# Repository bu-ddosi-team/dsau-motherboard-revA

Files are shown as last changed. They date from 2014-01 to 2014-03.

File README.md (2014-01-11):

# dSAU Motherboard (Rev. A)

## Directory Structure

- lib     : Contains Parts Library Files
- src     : Contains Schematics and PCBs
- docs    : Contains documentation and notes (PDFs of schematic/PCB, etc)
- prod    : Contains production files (Gerbers)

## Library Contents

### PcbLib

- VQFN64 (for ADS62P49)
- FCI_61083-101400LF
- MicroZed Mating Side

### SchLib

- ADS62P49
- MicroZed

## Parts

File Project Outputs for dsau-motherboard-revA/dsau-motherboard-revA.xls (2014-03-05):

Designator | Quantity | Description | Manufacturer 1 | Manufacturer Part Number | Supplier 1 | Supplier Part Number 1
C1_1 | 1.0 | Capacitor | Yageo | CC0603ZRY5V9BB104 | Digi-Key | 311-1343-1-ND
C1_2 | 1.0 | Capacitor | Yageo | CC0603ZRY5V9BB104 | Digi-Key | 311-1343-1-ND
C2_1 | 1.0 | Capacitor | Yageo | CC0603ZRY5V9BB104 | Digi-Key | 311-1343-1-ND
C2_2 | 1.0 | Capacitor | Yageo | CC0603ZRY5V9BB104 | Digi-Key | 311-1343-1-ND
C3_1 | 1.0 | Capacitor | Yageo | CC0603ZRY5V9BB104 | Digi-Key | 311-1343-1-ND
C3_2 | 1.0 | Capacitor | Yageo | CC0603ZRY5V9BB104 | Digi-Key | 311-1343-1-ND
C4 | 1.0 | Polarized Capacitor (Surface Mount) | AVX Corporation | TPSA336K006R0600 | Digi-Key | 478-1755-1-ND
C5 | 1.0 | Capacitor | Yageo | CC0603ZRY5V9BB104 | Digi-Key | 311-1343-1-ND
C6 | 1.0 | Polarized Capacitor (Surface Mount) | AVX Corporation | TPSA336K006R0600 | Digi-Key | 478-1755-1-ND
C7 | 1.0 | Capacitor | Yageo | CC0603ZRY5V9BB104 | Digi-Key | 311-1343-1-ND
C8 | 1.0 | Capacitor | Yageo | CC0805KKX7R7BB105 | Digi-Key | 311-1365-1-ND
C9 | 1.0 | Capacitor | Kemet | C0603C103K3GACTU | Digi-Key | 399-8987-1-ND
C10 | 1.0 | Capacitor | Samsung Electro-Mechanics America, Inc | CL10C100JB8NCNC | Digi-Key | 1276-2154-1-ND
C11 | 1.0 | Capacitor | Yageo | CC0805KKX7R7BB105 | Digi-Key | 311-1365-1-ND
C12 | 1.0 | Capacitor | Yageo | CC0603ZRY5V9BB104 | Digi-Key | 311-1343-1-ND
C13 | 1.0 | Capacitor | Kemet | C0603C103K3GACTU | Digi-Key | 399-8987-1-ND
C14 | 1.0 | Capacitor | Samsung Electro-Mechanics America, Inc | CL10C100JB8NCNC | Digi-Key | 1276-2154-1-ND
C15 | 1.0 | Polarized Capacitor (Surface Mount) | AVX Corporation | TPSA336K006R0600 | Digi-Key | 478-1755-1-ND
C16 | 1.0 | Capacitor | Kemet | C0603C103K3GACTU | Digi-Key | 399-8987-1-ND
C17 | 1.0 | Capacitor | Yageo | CC0603ZRY5V9BB104 | Digi-Key | 311-1343-1-ND
C18 | 1.0 | Capacitor | Yageo | CC0603ZRY5V9BB104 | Digi-Key | 311-1343-1-ND
C19 | 1.0 | Capacitor | Yageo | CC0603ZRY5V9BB104 | Digi-Key | 311-1343-1-ND
C20 | 1.0 | Capacitor | Yageo | CC0603ZRY5V9BB104 | Digi-Key | 311-1343-1-ND
C21 | 1.0 | Capacitor | Yageo | CC0603ZRY5V9BB104 | Digi-Key | 311-1343-1-ND
C22 | 1.0 | Polarized Capacitor (Surface Mount) | Vishay Sprague | TL8A0107M010C | Digi-Key | 718-1921-1-ND
C23 | 1.0 |  | TDK Corporation | C1005X5R1A104K | Digi-Key | 445-1265-1-ND
C24 | 1.0 | GRM1555C1E5R1CA0 | Kemet | C0402C519C5GACTU | Digi-Key | 399-8972-1-ND
C25 | 1.0 | GRM31CR60J476ME1 | Murata Electronics North America | GRM31CR60J476ME19L | Digi-Key | 490-3907-1-ND
C26 | 1.0 | C3225X5R1A226M | TDK Corporation | C3225X5R1A226M | Digi-Key | 445-1403-1-ND
C27 | 1.0 | GRM155R61A105KE1 | Murata Electronics North America | GRM155R61A105KE15D | Digi-Key | 490-3890-1-ND
C28 | 1.0 | GRM155R71E822KA0 | Murata Electronics North America | GRM155R71E822KA01D | Digi-Key | 490-1311-1-ND
C29 | 1.0 | Capacitor | Samsung Electro-Mechanics America, Inc | CL10A106MQ8NNNC | Digi-Key | 1276-1119-1-ND
C30 | 1.0 |  | TDK Corporation | C1005X5R1A104K | Digi-Key | 445-1265-1-ND
C31 | 1.0 | Capacitor | TDK Corporation | C3216X5R0J686M160AB | Digi-Key | 445-14671-1-ND
C32 | 1.0 | GRM1555C1E5R1CA0 | Kemet | C0402C519C5GACTU | Digi-Key | 399-8972-1-ND
C33 | 1.0 | GRM31CR60J476ME1 | Murata Electronics North America | GRM31CR60J476ME19L | Digi-Key | 490-3907-1-ND
C34 | 1.0 | C3225X5R1A226M | TDK Corporation | C3225X5R1A226M | Digi-Key | 445-1403-1-ND
C35 | 1.0 | GRM155R61A105KE1 | Murata Electronics North America | GRM155R61A105KE15D | Digi-Key | 490-3890-1-ND
C36 | 1.0 | GRM155R71E822KA0 | Murata Electronics North America | GRM155R71E822KA01D | Digi-Key | 490-1311-1-ND
C37 | 1.0 | Capacitor | Yageo | CC0603ZRY5V9BB104 | Digi-Key | 311-1343-1-ND
C38 | 1.0 | Capacitor | Yageo | CC0603ZRY5V9BB104 | Digi-Key | 311-1343-1-ND
C39 | 1.0 | Capacitor | Yageo | CC0603ZRY5V9BB104 | Digi-Key | 311-1343-1-ND
C40 | 1.0 | Polarized Capacitor (Surface Mount) | AVX Corporation | TPSA336K006R0600 | Digi-Key | 478-1755-1-ND
C41 | 1.0 | Polarized Capacitor (Surface Mount) | Vishay Sprague | TL8A0107M010C | Digi-Key | 718-1921-1-ND
C42 | 1.0 | Capacitor | Yageo | CC0603ZRY5V9BB104 | Digi-Key | 311-1343-1-ND
C43 | 1.0 | Capacitor | Yageo | CC0603ZRY5V9BB104 | Digi-Key | 311-1343-1-ND
C44 | 1.0 | Capacitor | Yageo | CC0603ZRY5V9BB104 | Digi-Key | 311-1343-1-ND
C45 | 1.0 | Capacitor | Yageo | CC0603ZRY5V9BB104 | Digi-Key | 311-1343-1-ND
C46 | 1.0 | Capacitor | Yageo | CC0603ZRY5V9BB104 | Digi-Key | 311-1343-1-ND
C47 | 1.0 | Capacitor | Yageo | CC0603ZRY5V9BB104 | Digi-Key | 311-1343-1-ND
C48 | 1.0 | Capacitor | Kemet | C0603C103K3GACTU | Digi-Key | 399-8987-1-ND
C49 | 1.0 | Capacitor | Samsung Electro-Mechanics America, Inc | CL10C100JB8NCNC | Digi-Key | 1276-2154-1-ND
C50 | 1.0 | Capacitor | Samsung Electro-Mechanics America, Inc | CL10C100JB8NCNC | Digi-Key | 1276-2154-1-ND
C51 | 1.0 | Capacitor | Samsung Electro-Mechanics America, Inc | CL10C100JB8NCNC | Digi-Key | 1276-2154-1-ND
C52 | 1.0 | Capacitor | Kemet | C0603C103K3GACTU | Digi-Key | 399-8987-1-ND
C53 | 1.0 | Capacitor | Kemet | C0603C103K3GACTU | Digi-Key | 399-8987-1-ND
C54 | 1.0 | Capacitor | Kemet | C0603C103K3GACTU | Digi-Key | 399-8987-1-ND
C55 | 1.0 | Polarized Capacitor (Surface Mount) | AVX Corporation | TPSA336K006R0600 | Digi-Key | 478-1755-1-ND
C56 | 1.0 | Capacitor | Yageo | CC0603ZRY5V9BB104 | Digi-Key | 311-1343-1-ND
C57 | 1.0 | Capacitor | Yageo | CC0603ZRY5V9BB104 | Digi-Key | 311-1343-1-ND
C58 | 1.0 | Capacitor | Kemet | C0603C103K3GACTU | Digi-Key | 399-8987-1-ND
C59 | 1.0 | Capacitor | Samsung Electro-Mechanics America, Inc | CL10C100JB8NCNC | Digi-Key | 1276-2154-1-ND
C60 | 1.0 | Capacitor | Yageo | CC0603ZRY5V9BB104 | Digi-Key | 311-1343-1-ND
C61 | 1.0 | Capacitor | Kemet | C0603C103K3GACTU | Digi-Key | 399-8987-1-ND
C62 | 1.0 | Capacitor | Yageo | CC0603ZRY5V9BB104 | Digi-Key | 311-1343-1-ND
C63 | 1.0 | Capacitor | Kemet | C0603C103K3GACTU | Digi-Key | 399-8987-1-ND
C64 | 1.0 | Capacitor | Yageo | CC0603ZRY5V9BB104 | Digi-Key | 311-1343-1-ND
C65 | 1.0 | Capacitor | Kemet | C0603C103K3GACTU | Digi-Key | 399-8987-1-ND
C66 | 1.0 | Capacitor | Yageo | CC0805KKX7R7BB105 | Digi-Key | 311-1365-1-ND
C67 | 1.0 | Capacitor | Yageo | CC0603ZRY5V9BB104 | Digi-Key | 311-1343-1-ND
C68 | 1.0 | Capacitor | Samsung Electro-Mechanics America, Inc | CL10C100JB8NCNC | Digi-Key | 1276-2154-1-ND
C69 | 1.0 | Polarized Capacitor (Surface Mount) | AVX Corporation | TPSA336K006R0600 | Digi-Key | 478-1755-1-ND
C70 | 1.0 | Capacitor | Yageo | CC0805KKX7R7BB105 | Digi-Key | 311-1365-1-ND
C71 | 1.0 | Capacitor | Yageo | CC0603ZRY5V9BB104 | Digi-Key | 311-1343-1-ND
C72 | 1.0 | Capacitor | Samsung Electro-Mechanics America, Inc | CL10C100JB8NCNC | Digi-Key | 1276-2154-1-ND
C73 | 1.0 | Capacitor | Yageo | CC0805KKX7R7BB105 | Digi-Key | 311-1365-1-ND
C74 | 1.0 | Capacitor | Yageo | CC0603ZRY5V9BB104 | Digi-Key | 311-1343-1-ND
C75 | 1.0 | Capacitor | Samsung Electro-Mechanics America, Inc | CL10C100JB8NCNC | Digi-Key | 1276-2154-1-ND
C76 | 1.0 | Capacitor | Yageo | CC0603ZRY5V9BB104 | Digi-Key | 311-1343-1-ND
C77 | 1.0 | Capacitor | Yageo | CC0603ZRY5V9BB104 | Digi-Key | 311-1343-1-ND
D1 | 1.0 | Typical INFRARED GaAs LED | Kingbright Company LLC | APT3216YC | Digi-Key | 754-1145-1-ND
D2 | 1.0 | Typical INFRARED GaAs LED | Kingbright Company LLC | APT3216YC | Digi-Key | 754-1145-1-ND
D3 | 1.0 | Typical INFRARED GaAs LED | Kingbright Company LLC | APT3216YC | Digi-Key | 754-1145-1-ND
D4 | 1.0 | The Blue source color devices are made with InGaN Light Emitting Diode. The Green source color devices are made with InGaN on Sapphire Light Emitting Diode. The Hyper Red source color devices are made with Al- GaInP on GaAs substrate Ligh | Loading... | APTF3216QBDZGSURKC | Mouser | 604-APTF3216QBDZGSUR
D5 | 1.0 | Typical INFRARED GaAs LED | Kingbright Company LLC | APL3015SGC-F01 | Digi-Key | 754-1111-1-ND
D6 | 1.0 | Typical INFRARED GaAs LED | Kingbright Company LLC | APL3015SGC-F01 | Digi-Key | 754-1111-1-ND
D7 | 1.0 | Typical INFRARED GaAs LED | Kingbright Company LLC | APL3015SGC-F01 | Digi-Key | 754-1111-1-ND
D8 | 1.0 | Typical INFRARED GaAs LED | Kingbright Company LLC | APL3015SGC-F01 | Digi-Key | 754-1111-1-ND
J1_1 | 1.0 | Header, 10-Pin, Dual row | Loading... | EJH-110-01-F-D-SM-LC | Samtec | EJH-110-01-F-D-SM-LC
J1_2 | 1.0 | Header, 10-Pin, Dual row | Loading... | EJH-110-01-F-D-SM-LC | Samtec | EJH-110-01-F-D-SM-LC
J1_3 | 1.0 | Header, 10-Pin, Dual row | Loading... | EJH-110-01-F-D-SM-LC | Samtec | EJH-110-01-F-D-SM-LC
J1_4 | 1.0 | Header, 10-Pin, Dual row | Loading... | EJH-110-01-F-D-SM-LC | Samtec | EJH-110-01-F-D-SM-LC
J1_5 | 1.0 | Header, 10-Pin, Dual row | Loading... | EJH-110-01-F-D-SM-LC | Samtec | EJH-110-01-F-D-SM-LC
J1_6 | 1.0 | Header, 10-Pin, Dual row | Loading... | EJH-110-01-F-D-SM-LC | Samtec | EJH-110-01-F-D-SM-LC
J2_1 | 1.0 | SMB Straight Connector | Molex Inc | 0731000207 | Digi-Key | WM5528-ND
J2_2 | 1.0 | SMB Straight Connector | Molex Inc | 0731000207 | Digi-Key | WM5528-ND
J2_3 | 1.0 | SMB Straight Connector | Molex Inc | 0731000207 | Digi-Key | WM5528-ND
J2_4 | 1.0 | SMB Straight Connector | Molex Inc | 0731000207 | Digi-Key | WM5528-ND
J2_5 | 1.0 | SMB Straight Connector | Molex Inc | 0731000207 | Digi-Key | WM5528-ND
J2_6 | 1.0 | SMB Straight Connector | Molex Inc | 0731000207 | Digi-Key | WM5528-ND
J3 | 1.0 | SMB Straight Connector | Molex Inc | 0733910060 | Digi-Key | WM5543-ND
J4 | 1.0 | Header, 3-Pin | CUI Inc | PJ-002BH | Digi-Key | CP-002BH-ND
J5 | 1.0 | Header, 2-Pin | Molex Inc | 0010085021 | Digi-Key | WM4333-ND
J6 | 1.0 | SMB Straight Connector | Molex Inc | 0733910320 | Digi-Key | WM8554-ND
J7 | 1.0 | SMB Straight Connector | Molex Inc | 0733910320 | Digi-Key | WM8554-ND
J8 | 1.0 | SMB Straight Connector | Molex Inc | 0733910060 | Digi-Key | WM5543-ND
J9 | 1.0 | Header, 13-Pin, Dual row | Loading... |  | Stock | 2x13 pin 100mil Headers
J10 | 1.0 | Header, 6-Pin | Loading... |  | Stock | 6 pin 100 mil
J11 | 1.0 | Header, 2-Pin | Molex Inc | 0010085021 | Digi-Key | WM4333-ND
J12 | 1.0 | Header, 2-Pin | Molex Inc | 0010085021 | Digi-Key | WM4333-ND
J13 | 1.0 | Header, 2-Pin | Molex Inc | 0010085021 | Digi-Key | WM4333-ND
JP1 | 1.0
JP2 | 1.0
JP3 | 1.0
JP4 | 1.0
JP5 | 1.0
JP6 | 1.0
L1 | 1.0 | Magnetic-Core Inductor | Laird-Signal Integrity Products | MI0603L301R-10 | Digi-Key | 240-2374-1-ND
L2 | 1.0 | Magnetic-Core Inductor | Laird-Signal Integrity Products | MI0603L301R-10 | Digi-Key | 240-2374-1-ND
L3 | 1.0 | Magnetic-Core Inductor | Laird-Signal Integrity Products | MI0603L301R-10 | Digi-Key | 240-2374-1-ND
L4 | 1.0 | SRN6045-2R2Y | Bourns Inc. | SRN6045-2R2Y | Digi-Key | SRN6045-2R2YCT-ND
L5 | 1.0 | SRN6045-2R2Y | Bourns Inc. | SRN6045-2R2Y | Digi-Key | SRN6045-2R2YCT-ND
L6 | 1.0 | Magnetic-Core Inductor | Laird-Signal Integrity Products | MI0603L301R-10 | Digi-Key | 240-2374-1-ND
L7 | 1.0 | Magnetic-Core Inductor | Laird-Signal Integrity Products | MI0603L301R-10 | Digi-Key | 240-2374-1-ND
Q1 | 1.0 | N-Channel MOSFET 1.8V Logic Level | Alpha & Omega Semiconductor Inc | AO3416 | Digi-Key | 785-1011-1-ND
Q2 | 1.0 | N-Channel MOSFET 1.8V Logic Level | Alpha & Omega Semiconductor Inc | AO3416 | Digi-Key | 785-1011-1-ND
Q3 | 1.0 | N-Channel MOSFET 1.8V Logic Level | Alpha & Omega Semiconductor Inc | AO3416 | Digi-Key | 785-1011-1-ND
Q4 | 1.0 | N-Channel MOSFET 1.8V Logic Level | Alpha & Omega Semiconductor Inc | AO3416 | Digi-Key | 785-1011-1-ND
Q5 | 1.0 | N-Channel MOSFET 1.8V Logic Level | Alpha & Omega Semiconductor Inc | AO3416 | Digi-Key | 785-1011-1-ND
Q6 | 1.0 | N-Channel MOSFET 1.8V Logic Level | Alpha & Omega Semiconductor Inc | AO3416 | Digi-Key | 785-1011-1-ND
Q7 | 1.0 | N-Channel MOSFET 1.8V Logic Level | Alpha & Omega Semiconductor Inc | AO3416 | Digi-Key | 785-1011-1-ND
Q8 | 1.0 | N-Channel MOSFET 1.8V Logic Level | Alpha & Omega Semiconductor Inc | AO3416 | Digi-Key | 785-1011-1-ND
Q9 | 1.0 | N-Channel MOSFET 1.8V Logic Level | Alpha & Omega Semiconductor Inc | AO3416 | Digi-Key | 785-1011-1-ND
R1_1 | 1.0 | Resistor | Yageo | RC0603FR-0724R9L | Digi-Key | 311-24.9HRCT-ND
R1_2 | 1.0 | Resistor | Yageo | RC0603FR-0724R9L | Digi-Key | 311-24.9HRCT-ND
R2_1 | 1.0 | Resistor | Yageo | RC0603FR-0724R9L | Digi-Key | 311-24.9HRCT-ND
R2_2 | 1.0 | Resistor | Yageo | RC0603FR-0724R9L | Digi-Key | 311-24.9HRCT-ND
R3 | 1.0 | Resistor | Yageo | RC0603FR-07100RL | Digi-Key | 311-100HRCT-ND
R4 | 1.0 | Resistor | Yageo | 311-47kGRCT-ND | Digi-Key | 311-47KGRTR-ND
R5 | 1.0 | Resistor | Yageo | 311-47kGRCT-ND | Digi-Key | 311-47KGRTR-ND
R6 | 1.0 | CRCW040275K0FKED | Vishay Dale | CRCW040275K0FKED | Digi-Key | 541-75.0KLCT-ND
R7 | 1.0 | CRCW040222K1FKED | Vishay Dale | CRCW040222K1FKED | Digi-Key | 541-22.1KLCT-ND
R8 | 1.0 | CRCW040230K9FKED | Vishay Dale | CRCW040230K9FKED | Digi-Key | 541-30.9KLCT-ND
R9 | 1.0 | Resistor | Yageo | 311-47kGRCT-ND | Digi-Key | 311-47KGRTR-ND
R10 | 1.0 | CRCW040222K1FKED | Vishay Dale | CRCW040222K1FKED | Digi-Key | 541-22.1KLCT-ND
R11 | 1.0 | Resistor | Yageo | RT0603DRD0734KL | Digi-Key | 311-34KDCT-ND
R12 | 1.0 | Resistor | Yageo | RC0603JR-07100KL | Digi-Key | 311-100KGRCT-ND
R13 | 1.0 | Resistor | Yageo | 311-47kGRCT-ND | Digi-Key | 311-47KGRTR-ND
R14 | 1.0 | Resistor | Yageo | RC0603FR-0740K2L | Digi-Key | 311-40.2KHRCT-ND
R15 | 1.0 | Resistor | Yageo | RC0603FR-07220RL | Digi-Key | 311-220HRCT-ND
R16 | 1.0 | Resistor | Yageo | RC0603FR-07100RL | Digi-Key | 311-100HRCT-ND
R17 | 1.0 | Resistor | Yageo | RC0603FR-07100RL | Digi-Key | 311-100HRCT-ND
R18 | 1.0 | Resistor | Yageo | 311-47kGRCT-ND | Digi-Key | 311-47KGRTR-ND
R19 | 1.0 | Resistor | Yageo | RC0603FR-07220RL | Digi-Key | 311-220HRCT-ND
R20 | 1.0 | Resistor | Yageo | RC0603FR-07100RL | Digi-Key | 311-100HRCT-ND
R21 | 1.0 | Resistor | Yageo | RC0603FR-07100RL | Digi-Key | 311-100HRCT-ND
R22 | 1.0 | Resistor | Yageo | RC0603FR-07100RL | Digi-Key | 311-100HRCT-ND
R23 | 1.0 | Resistor | Yageo | 311-47kGRCT-ND | Digi-Key | 311-47KGRTR-ND
R24 | 1.0 | Resistor | Yageo | 311-47kGRCT-ND | Digi-Key | 311-47KGRTR-ND
R25 | 1.0 | Resistor | Yageo | 311-47kGRCT-ND | Digi-Key | 311-47KGRTR-ND
R26 | 1.0 | Resistor | Yageo | RC0603FR-07100RL | Digi-Key | 311-100HRCT-ND
R27 | 1.0 | Resistor | Yageo | RC0603FR-07100RL | Digi-Key | 311-100HRCT-ND
R28 | 1.0 | Resistor | Yageo | RC0603FR-07100RL | Digi-Key | 311-100HRCT-ND
R29 | 1.0 | Resistor | Yageo | RC0603FR-07100RL | Digi-Key | 311-100HRCT-ND
R30 | 1.0 | Resistor | Panasonic Electronic Components | ERJ-8ENF49R9V | Digi-Key | P49.9FCT-ND
R31 | 1.0 | Resistor | Yageo | 311-47kGRCT-ND | Digi-Key | 311-47KGRTR-ND
R32 | 1.0 | Resistor | Yageo | 311-47kGRCT-ND | Digi-Key | 311-47KGRTR-ND
R33 | 1.0 | Resistor | Yageo | 311-47kGRCT-ND | Digi-Key | 311-47KGRTR-ND
R34 | 1.0 | Resistor | Yageo | 311-47kGRCT-ND | Digi-Key | 311-47KGRTR-ND
R35 | 1.0 | Resistor | Yageo | 311-47kGRCT-ND | Digi-Key | 311-47KGRTR-ND
R36 | 1.0 | Resistor | Yageo | RC0603FR-07100RL | Digi-Key | 311-100HRCT-ND
R37 | 1.0 | Resistor | Yageo | RC0603JR-071KL | Digi-Key | 311-1.0KGRCT-ND
R38 | 1.0 | Resistor | Yageo | RC0603JR-071KL | Digi-Key | 311-1.0KGRCT-ND
R39 | 1.0 | Resistor | Yageo | RC0603JR-071KL | Digi-Key | 311-1.0KGRCT-ND
R40 | 1.0 | Resistor | Yageo | RC0603JR-071KL | Digi-Key | 311-1.0KGRCT-ND
R41 | 1.0 | Resistor | Yageo | RC0603JR-071KL | Digi-Key | 311-1.0KGRCT-ND
R42 | 1.0 | Resistor | Yageo | RC0603JR-071KL | Digi-Key | 311-1.0KGRCT-ND
R43 | 1.0 | Resistor | Panasonic Electronic Components | ERJ-8ENF49R9V | Digi-Key | P49.9FCT-ND
SW1 | 1.0 | Switch | TE Connectivity | FSM4JH | Digi-Key | 450-1650-ND
SW2 | 1.0 | Switch | TE Connectivity | FSM4JH | Digi-Key | 450-1650-ND
T1_1 | 1.0 | TRANSFORMR BALUN 2.3-2700MHZ SMD | Pulse Electronics Corporation | CX2156NL | Digi-Key | 553-1499-ND
T1_2 | 1.0 | TRANSFORMR BALUN 2.3-2700MHZ SMD | Pulse Electronics Corporation | CX2156NL | Digi-Key | 553-1499-ND
TP1 | 1.0 |  | Keystone Electronics | 5000 | Digi-Key | 5000K-ND
TP2 | 1.0 |  | Keystone Electronics | 5000 | Digi-Key | 5000K-ND
TP3 | 1.0 |  | Keystone Electronics | 5000 | Digi-Key | 5000K-ND
TP4 | 1.0 |  | Keystone Electronics | 5000 | Digi-Key | 5000K-ND
TP5 | 1.0 |  | Keystone Electronics | 5000 | Digi-Key | 5000K-ND
TP6 | 1.0 |  | Keystone Electronics | 5000 | Digi-Key | 5000K-ND
TP7 | 1.0 |  | Keystone Electronics | 5000 | Digi-Key | 5000K-ND
TP8 | 1.0 |  | Keystone Electronics | 5000 | Digi-Key | 5000K-ND
TP9 | 1.0 |  | Keystone Electronics | 5000 | Digi-Key | 5000K-ND
TP10 | 1.0 |  | Keystone Electronics | 5000 | Digi-Key | 5000K-ND
TP11 | 1.0 |  | Keystone Electronics | 5000 | Digi-Key | 5000K-ND
TP12 | 1.0 |  | Keystone Electronics | 5000 | Digi-Key | 5000K-ND
TP13 | 1.0 |  | Keystone Electronics | 5000 | Digi-Key | 5000K-ND
TP14 | 1.0 |  | Keystone Electronics | 5000 | Digi-Key | 5000K-ND
U1 | 1.0 | OSC 250 MHZ 3.3V LVDS SMD | Fox Electronics | FXO-LC736R-250 | Digi-Key | 631-1363-1-ND
U2 | 1.0 | IC ADC DUAL 14BIT 250MSPS 64VQFN | Texas Instruments | ADS62P49IRGCT | Digi-key | 296-24398-1-ND
U3 | 1.0 |  | IDT, Integrated Device Technology Inc |  | Digi-Key | 800-2561-ND
U4 | 1.0 | Imported | Texas Instruments | TPS54428DDAR | Digi-key | 296-30034-1-ND
U5 | 1.0 |  | Texas Instruments | LP3962EMP-3.3/NOPB | Digi-Key | LP3962EMP-3.3/NOPBCT-ND
U6 | 1.0 | Imported | Texas Instruments | TPS54428DDAR | Digi-key | 296-30034-1-ND
U7 | 1.0 |  | Linear Technology | LTC1728ES5-3.3#TRMPBF | Digi-Key | LTC1728ES5-3.3#TRMPBFCT-ND
U8 | 1.0 |  | Texas Instruments | TL331IDBVR | Digi-Key | 296-10168-1-ND
U9 | 1.0 | MicroZed is a low-cost development board based on the Xilinx Zynq-7000 All Programmable SoC. Its unique design allows it to be used as both a stand-alone evaluation board for basic SoC experimentation, or combined with a carrier card as an embeddable syst | Loading... |  | Avnet | AES-Z7MB-7Z010-G
U10 | 1.0 | This octal buffer/line driver is operational at 1.5-V to 3.6-V V CC , but is designed specifically for 1.65-V to 3.6-V V CC operation | Texas Instruments | SN74LVC244A | Digi-key | 296-1230-1-ND
U11 | 1.0 | This octal buffer/line driver is operational at 1.5-V to 3.6-V V CC , but is designed specifically for 1.65-V to 3.6-V V CC operation | Texas Instruments | SN74LVC244A | Digi-key | 296-1230-1-ND
U12 | 1.0 | This octal buffer/line driver is operational at 1.5-V to 3.6-V V CC , but is designed specifically for 1.65-V to 3.6-V V CC operation | Texas Instruments | SN74LVC244A | Digi-key | 296-1230-1-ND
U13 | 1.0 |  | Pericom | FNETHE025 | Digi-Key | FNETHE025CT-ND
U14 | 1.0 |  | IDT, Integrated Device Technology Inc | ICS83052I | Digi-Key | 800-1106-5-ND
U15 | 1.0 | Clock Fanout 1:6, 100MHz low-skew | Texas Instruments | CDCLVC1106 | Digi-Key | 296-27588-1-ND
U16 | 1.0 | This single-bit noninverting bus transceiver uses two separate configurable power-supply rails. The A port is designed to track VCCA. VCCA accepts any supply voltage from 1.65 V to 5.5 V. The B port is designed to track VCCB. VCCB accepts any supply vol | Loading... | SN74LVC1T45 | Digikey | 296-16843-1-ND

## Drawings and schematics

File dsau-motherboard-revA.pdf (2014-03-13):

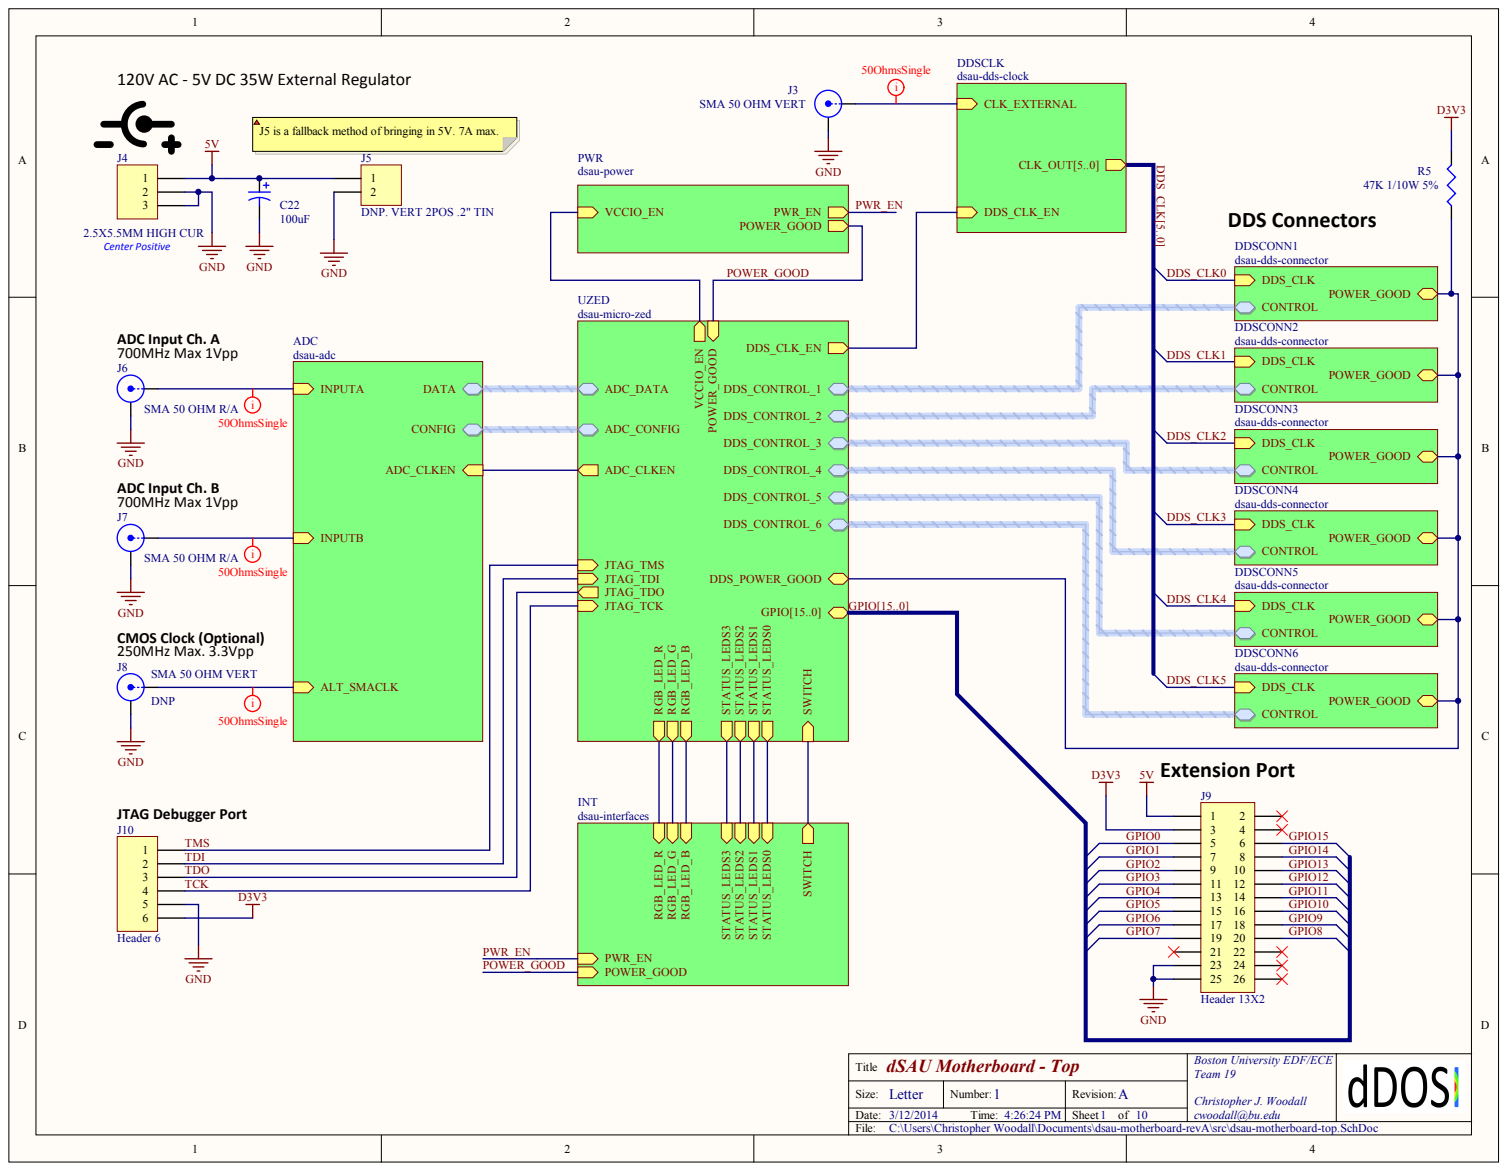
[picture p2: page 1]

120V AC - 5V DC 35W External Regulator

ALT_SMACLK

JTAG Debugger Port TMS TDI TDO TCK

INT dsau-i n terfaces

T it l e | Boston University EDF/ECE Team 19 Ch ristopher J. Woodall cwoodall@ bu.edu

Size : Letter | Number: | Rev i s i o n : A

3/12/201 4 T ime: 4:26:24 P M | | Sheet o f 10

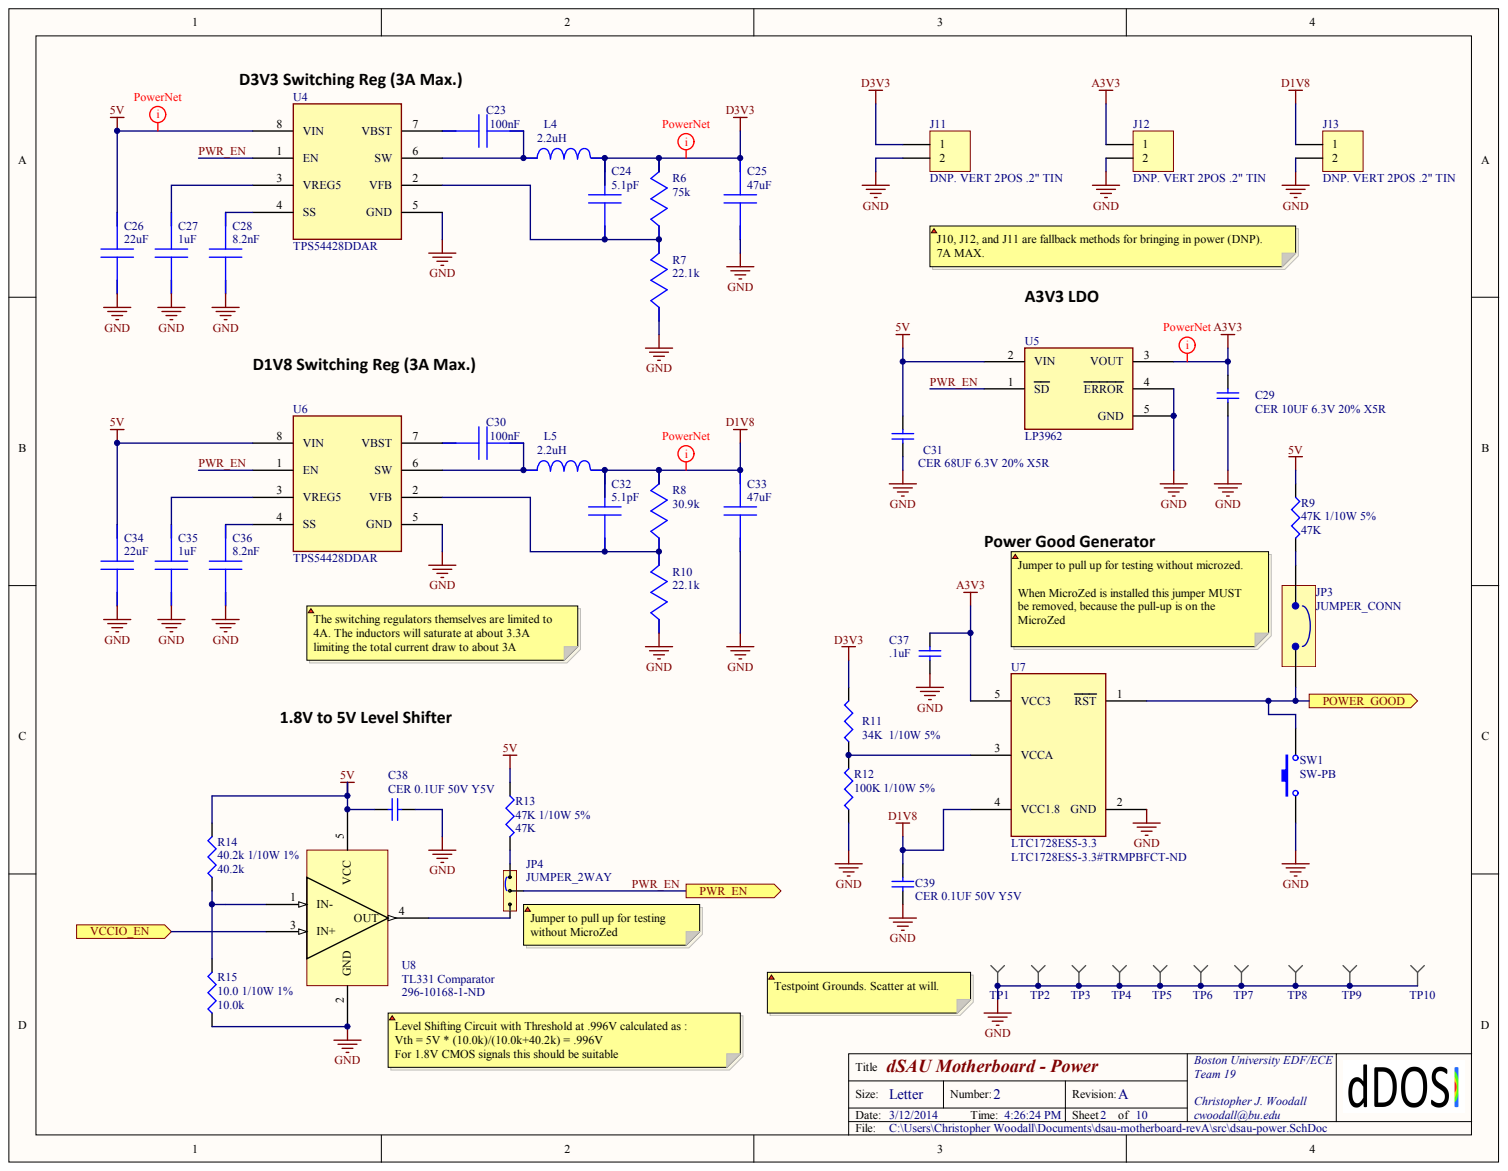
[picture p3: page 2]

J10, J12, and J11 are fallback methods for bringing in power (DNP).
7A MAX.

PWR_EN | EN 1 | i R8

Jumper to pull up for testing without microzed.

When MicroZed is installed this jumper MUST
be removed, because the pull-up is on the
MicroZed

The switching regulators themselves are limited to
4A. The inductors will saturate at about 3.3A
limiting the total current draw to about 3A

Jumper to pull up for testing
without MicroZed

Testpoint Grounds. Scatter at will.

Level Shifting Circuit with Threshold at .996V calculated as :
Vth = 5V * (10.0k)/(10.0k+40.2k) = .996V
For 1.8V CMOS signals this should be suitable

Title dSAU Motherboard - Power | Boston University EDF/ECE Christopher J. Woodall cwoodall@bu.edu

Size: | Number: 2 | Revision: A

Date: 3/12/2014 Time: 4:26:24 PM | | Sheet of 10

C:\Users\Christopher Woodall\Documents\dsau-motherboard-revA\src\dsau-power.SchDoc

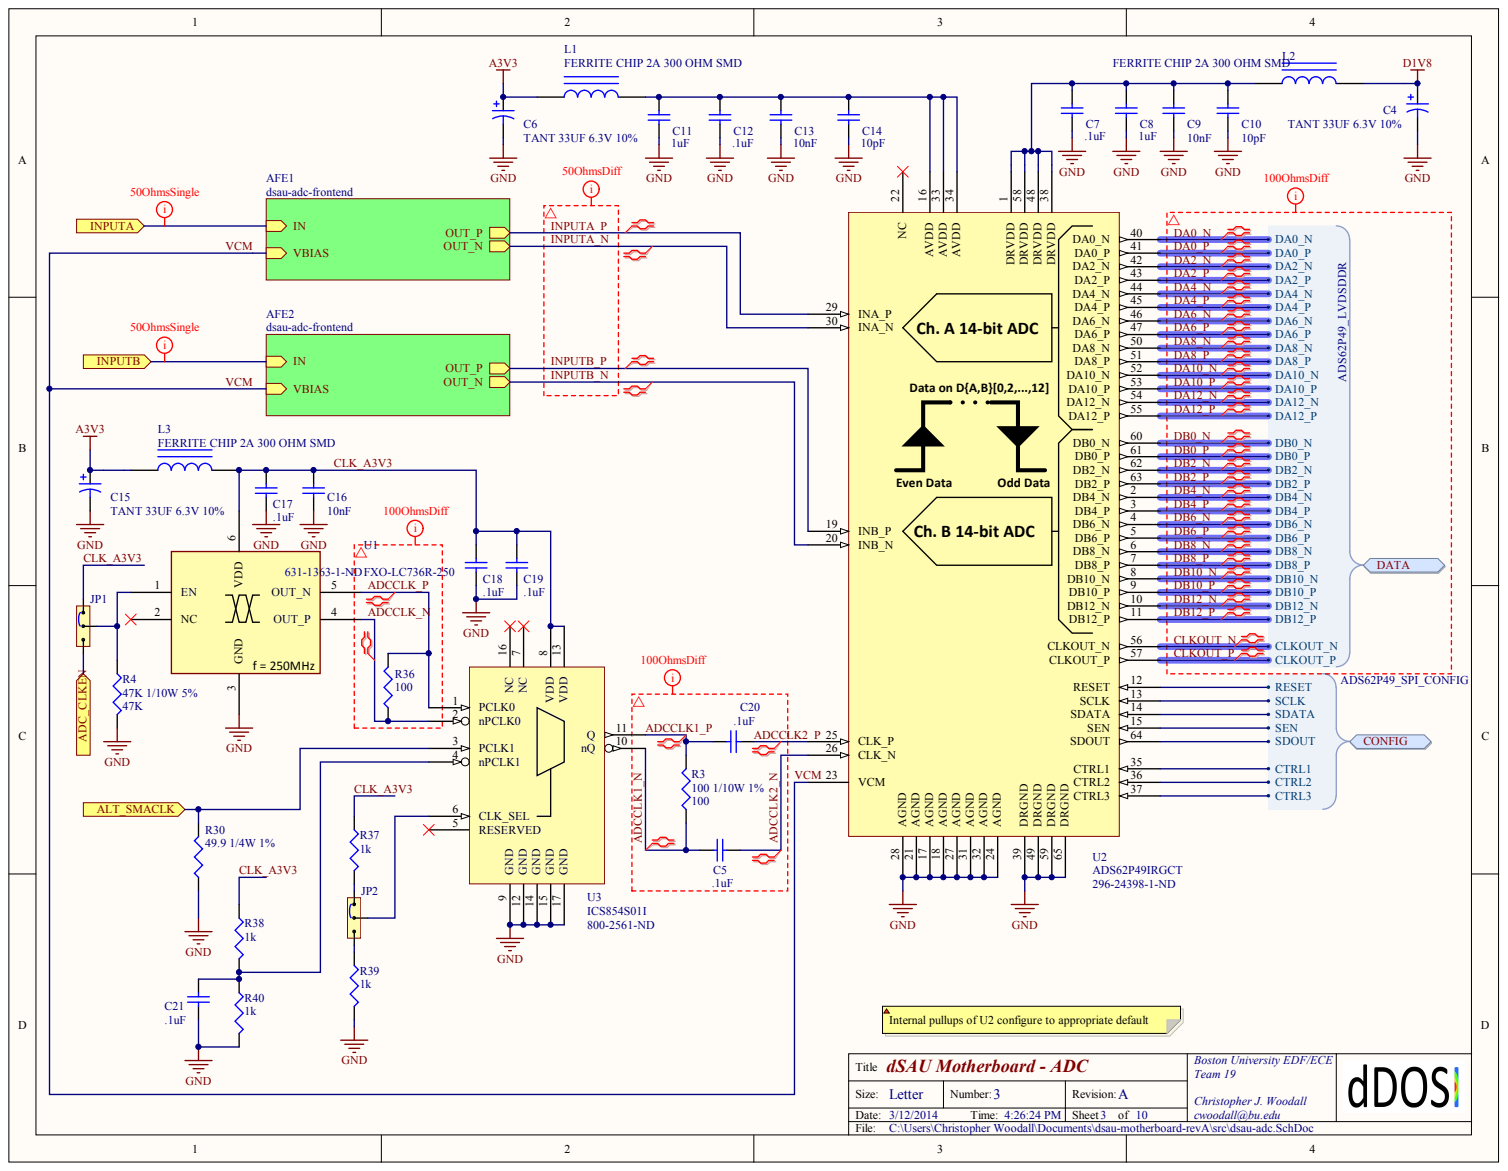
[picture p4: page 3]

FERRITE CHIP 2A 300 OHM SMD

L2 FERRITE CHIP 2A 300 OHM SMD

INA_N 30

INPUTB_P | INB_P 19
INPUTB_N

INB_N 20

C5 .1uF | CLK_N 26

nPCLK1 4

CLK_A3V3 | RESERVED 5 CLK_SEL 6

Internal pullups of U2 configure to appropriate default

Boston University EDF/ECE

C:\Users\Christopher Woodall\Documents\dsau-motherboard-revA\src\dsau-adc.SchDoc

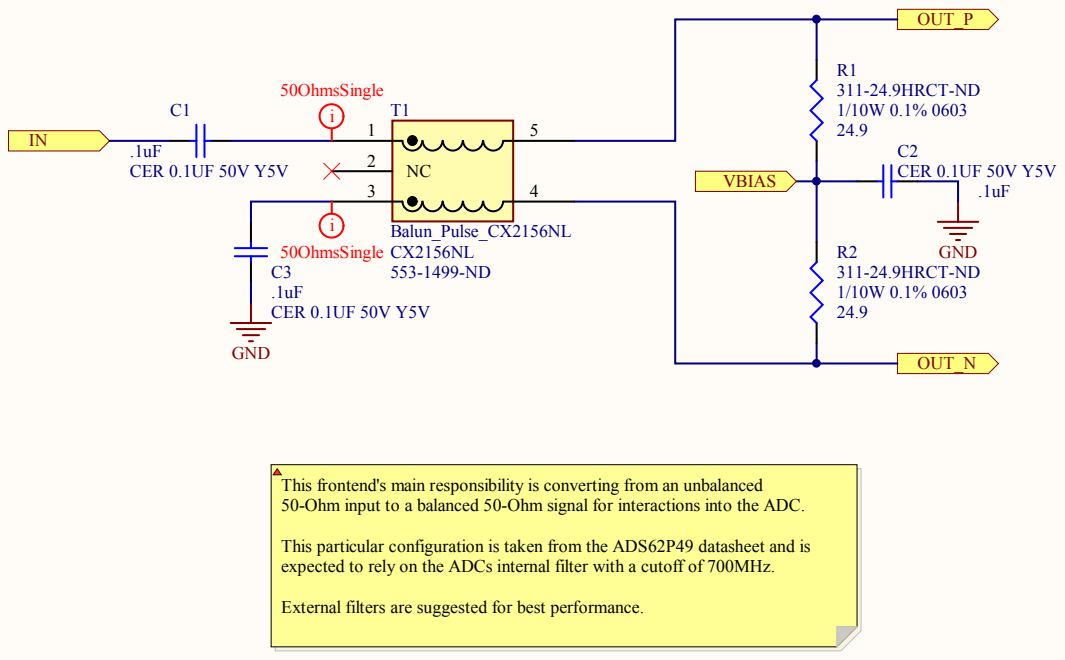
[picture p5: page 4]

This frontend's main responsibility is converting from an unbalanced
50-Ohm input to a balanced 50-Ohm signal for interactions into the ADC.

This particular configuration is taken from the ADS62P49 datasheet and is
expected to rely on the ADCs internal filter with a cutoff of 700MHz.

External filters are suggested for best performance.

dSAU Motherboard - ADC Frontend
Title

Boston University EDF/ECE

C:\Users\Christopher Woodall\Documents\dsau-motherboard-revA\src\dsau-adc-frontend.SchDoc

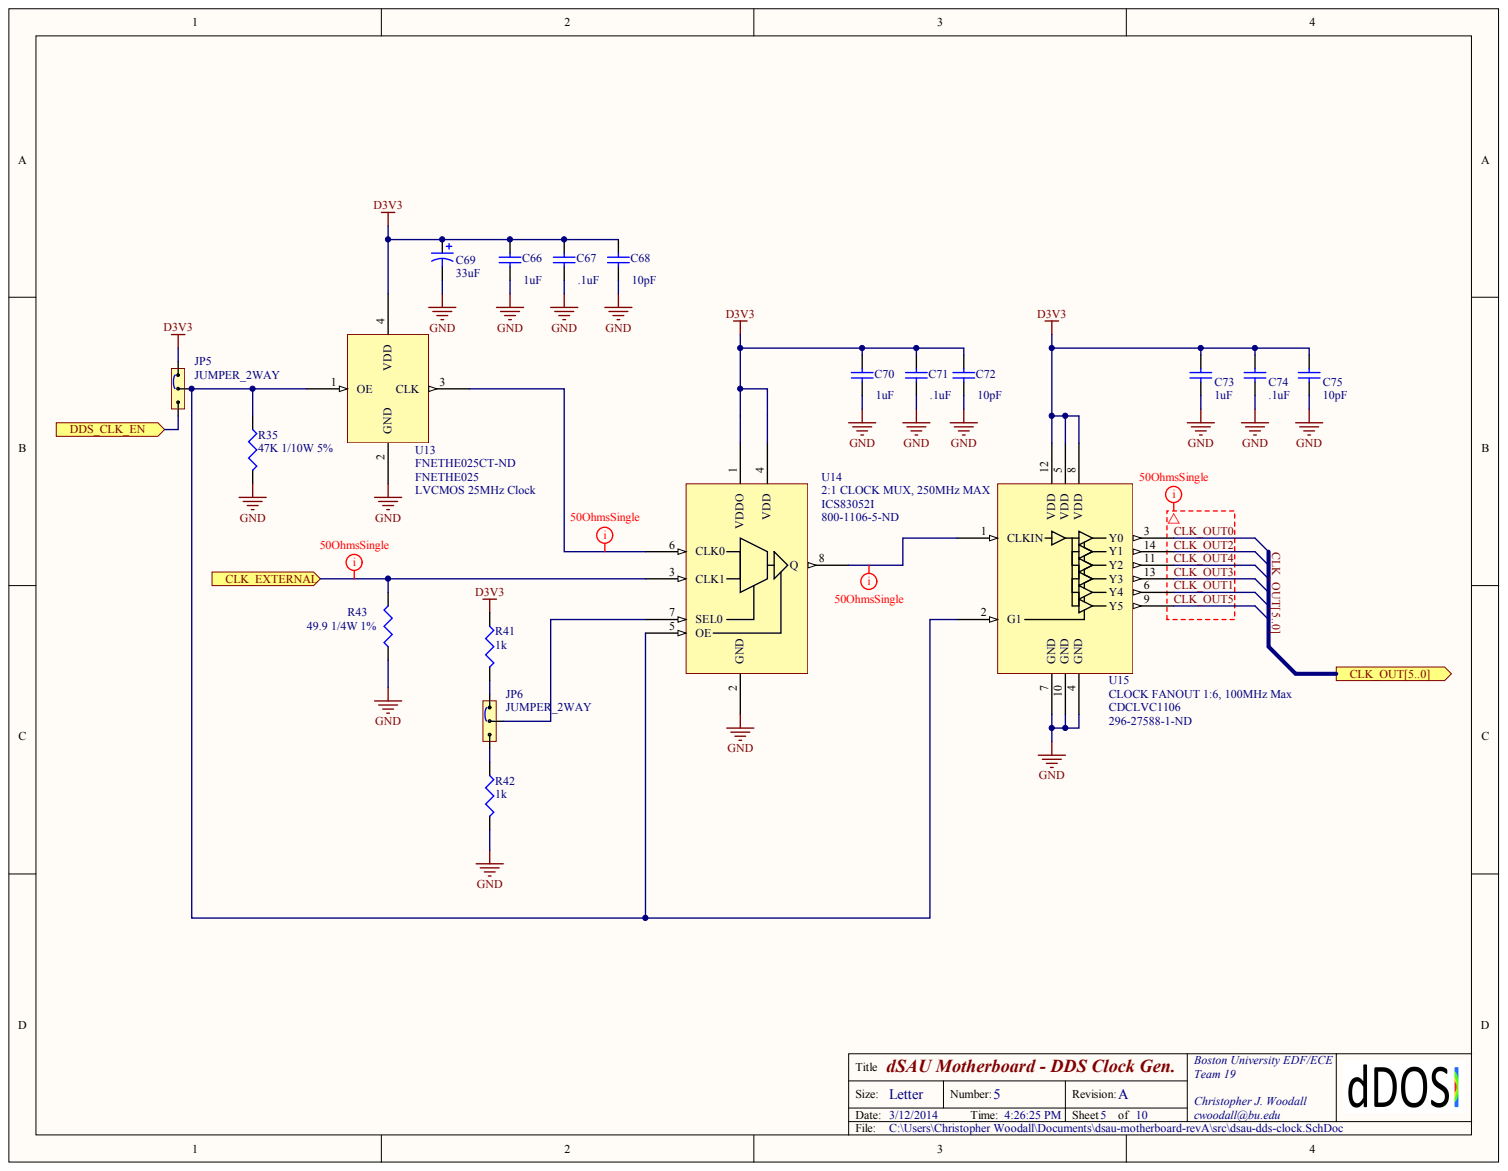
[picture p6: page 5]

CLK_OUT1
CLK_OUT5

dSAU Motherboard - DDS Clock Gen.
Title

Boston University EDF/ECE

C:\Users\Christopher Woodall\Documents\dsau-motherboard-revA\src\dsau-dds-clock.SchDoc

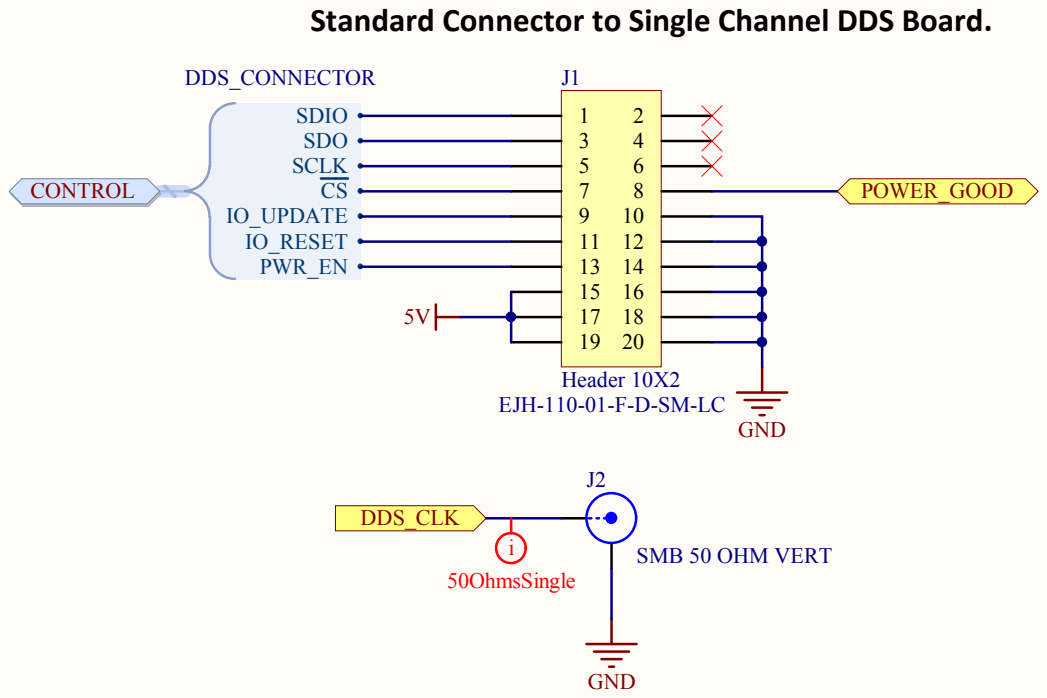
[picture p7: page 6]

Standard Connector to Single Channel DDS Board.

dSAU Motherboard - DDS Connector
Title

Boston University EDF/ECE

C:\Users\Christopher Woodall\Documents\dsau-motherboard-revA\src\dsau-dds-connector.SchDoc

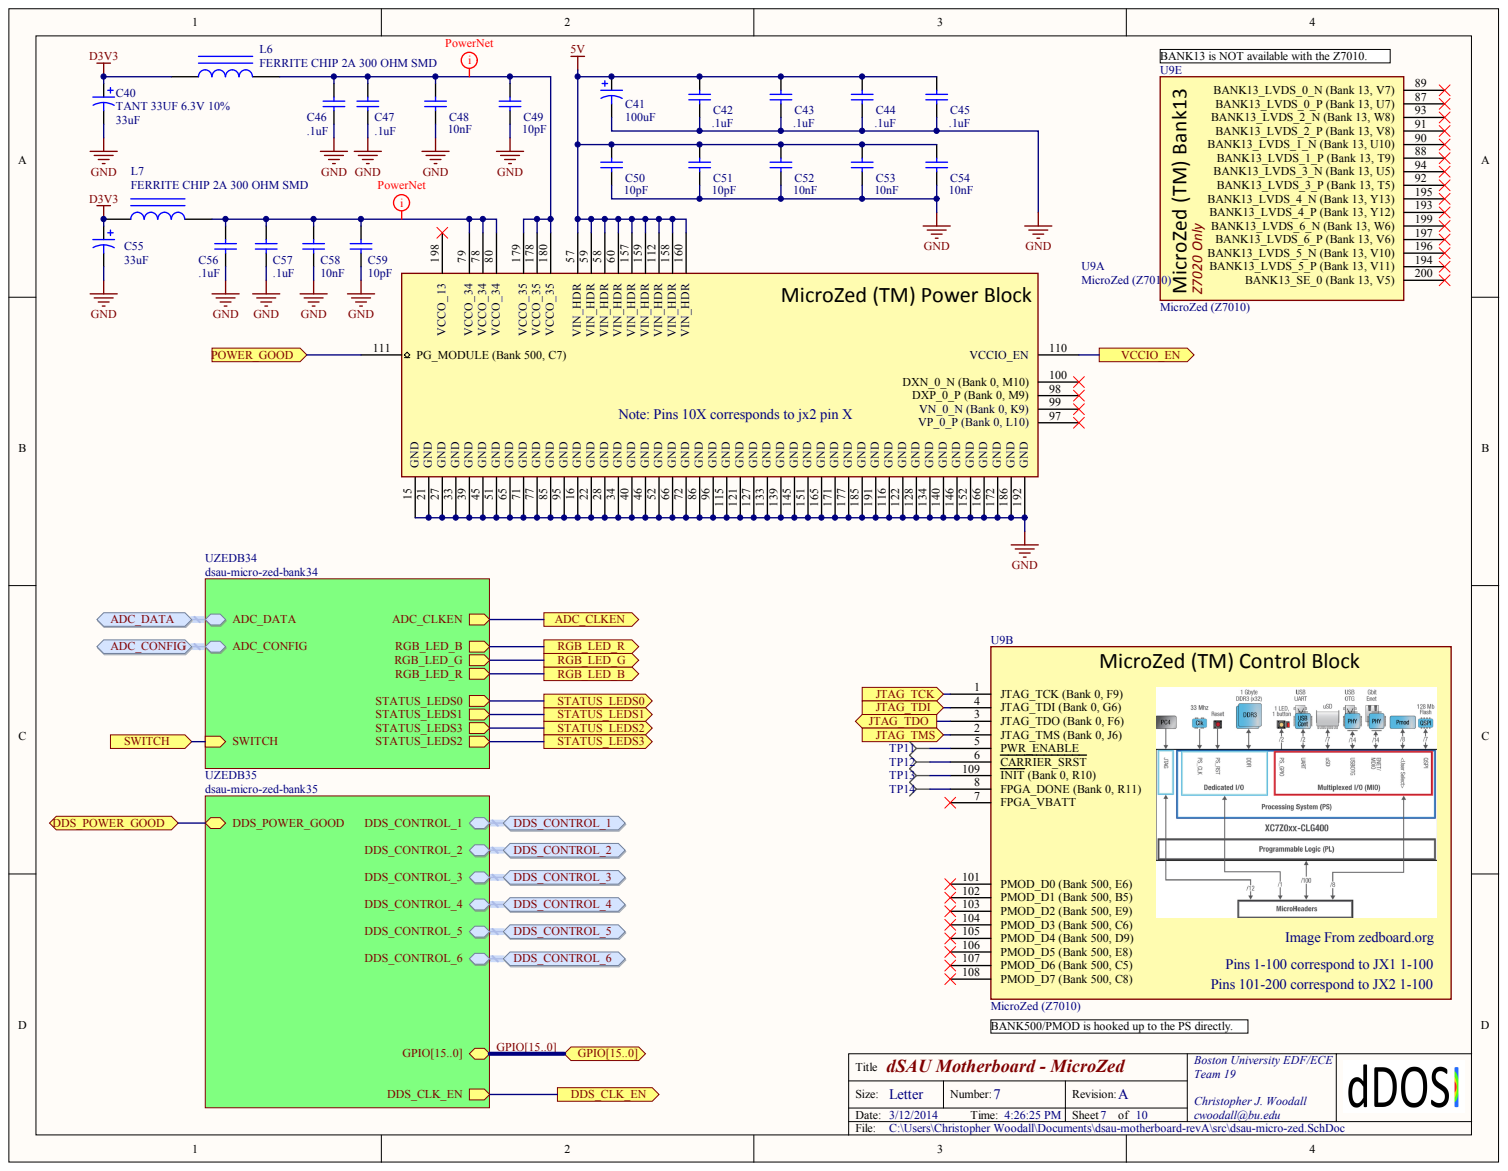
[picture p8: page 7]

FERRITE CHIP 2A 300 OHM SMD

BANK13 is NOT available with the Z7010.

MicroZed (TM) Power Block

Note: Pins 10X corresponds to jx2 pin X

MicroZed (TM) Control Block

Image From zedboard.org

MicroZed (Z7010)
BANK500/PMOD is hooked up to the PS directly.

Boston University EDF/ECE

C:\Users\Christopher Woodall\Documents\dsau-motherboard-revA\src\dsau-micro-zed.SchDoc

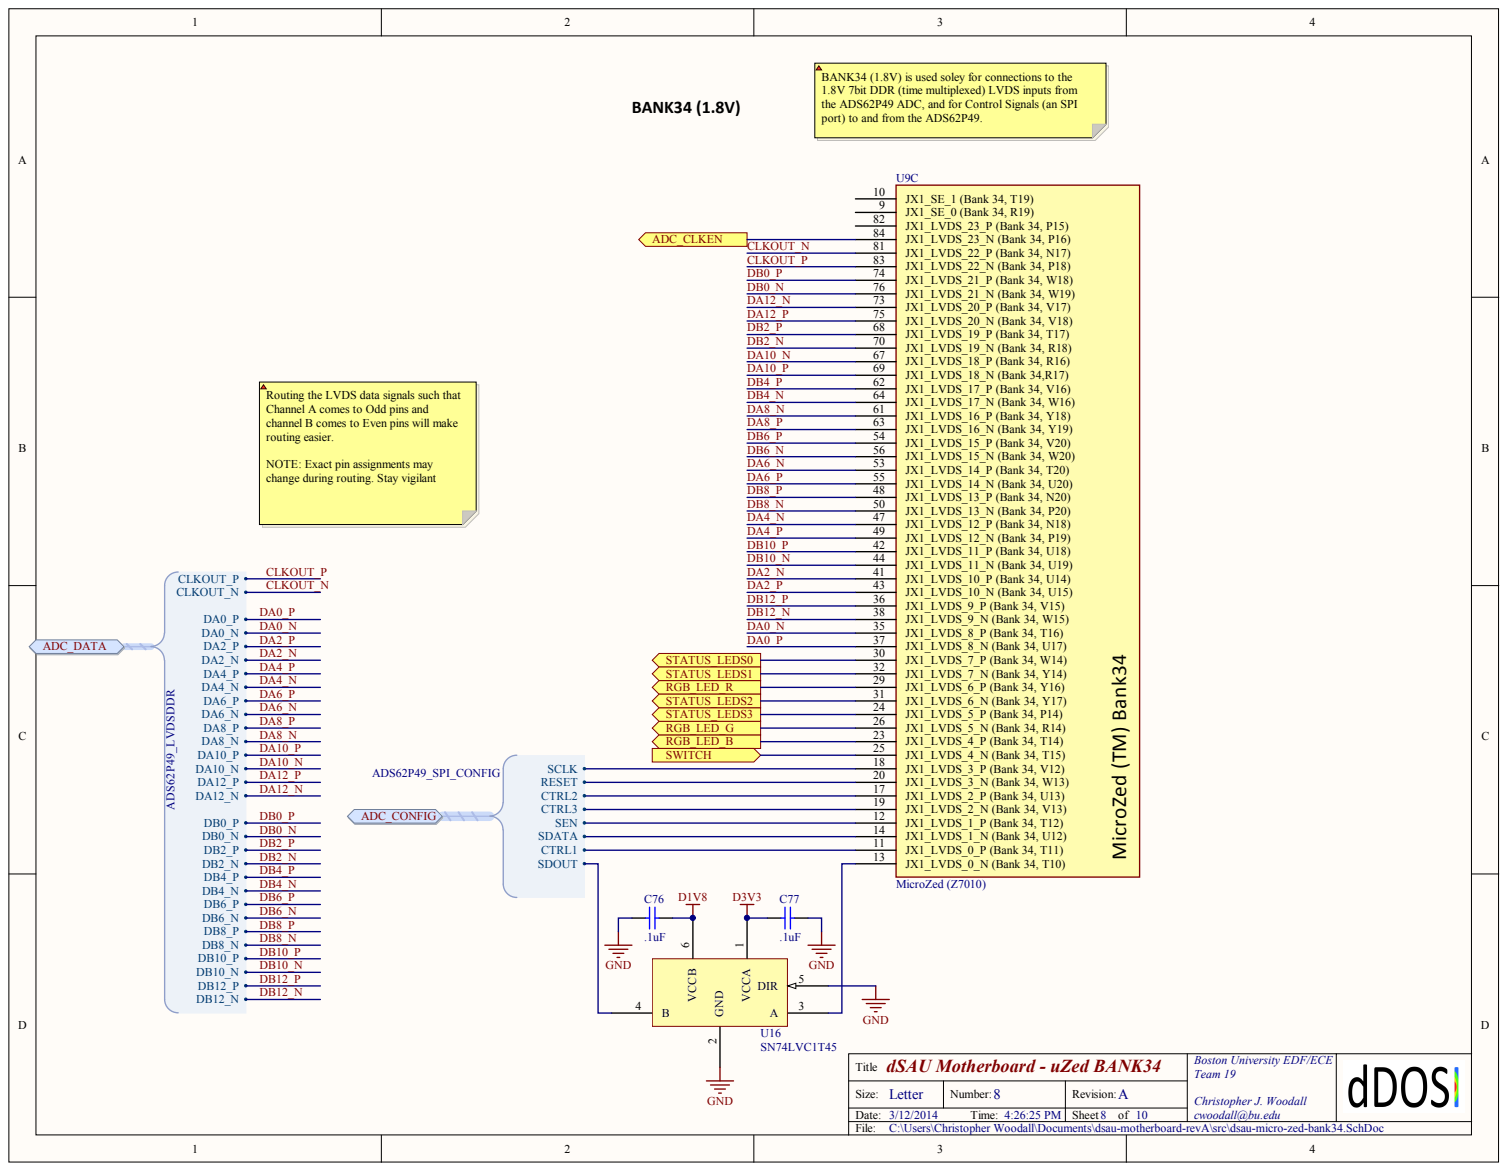
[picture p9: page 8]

BANK34 (1.8V) is used soley for connections to the
1.8V 7bit DDR (time multiplexed) LVDS inputs from
the ADS62P49 ADC, and for Control Signals (an SPI
port) to and from the ADS62P49.

Routing the LVDS data signals such that
Channel A comes to Odd pins and
channel B comes to Even pins will make
routing easier.

NOTE: Exact pin assignments may
change during routing. Stay vigilant

Boston University EDF/ECE

C:\Users\Christopher Woodall\Documents\dsau-motherboard-revA\src\dsau-micro-zed-bank34.SchDoc

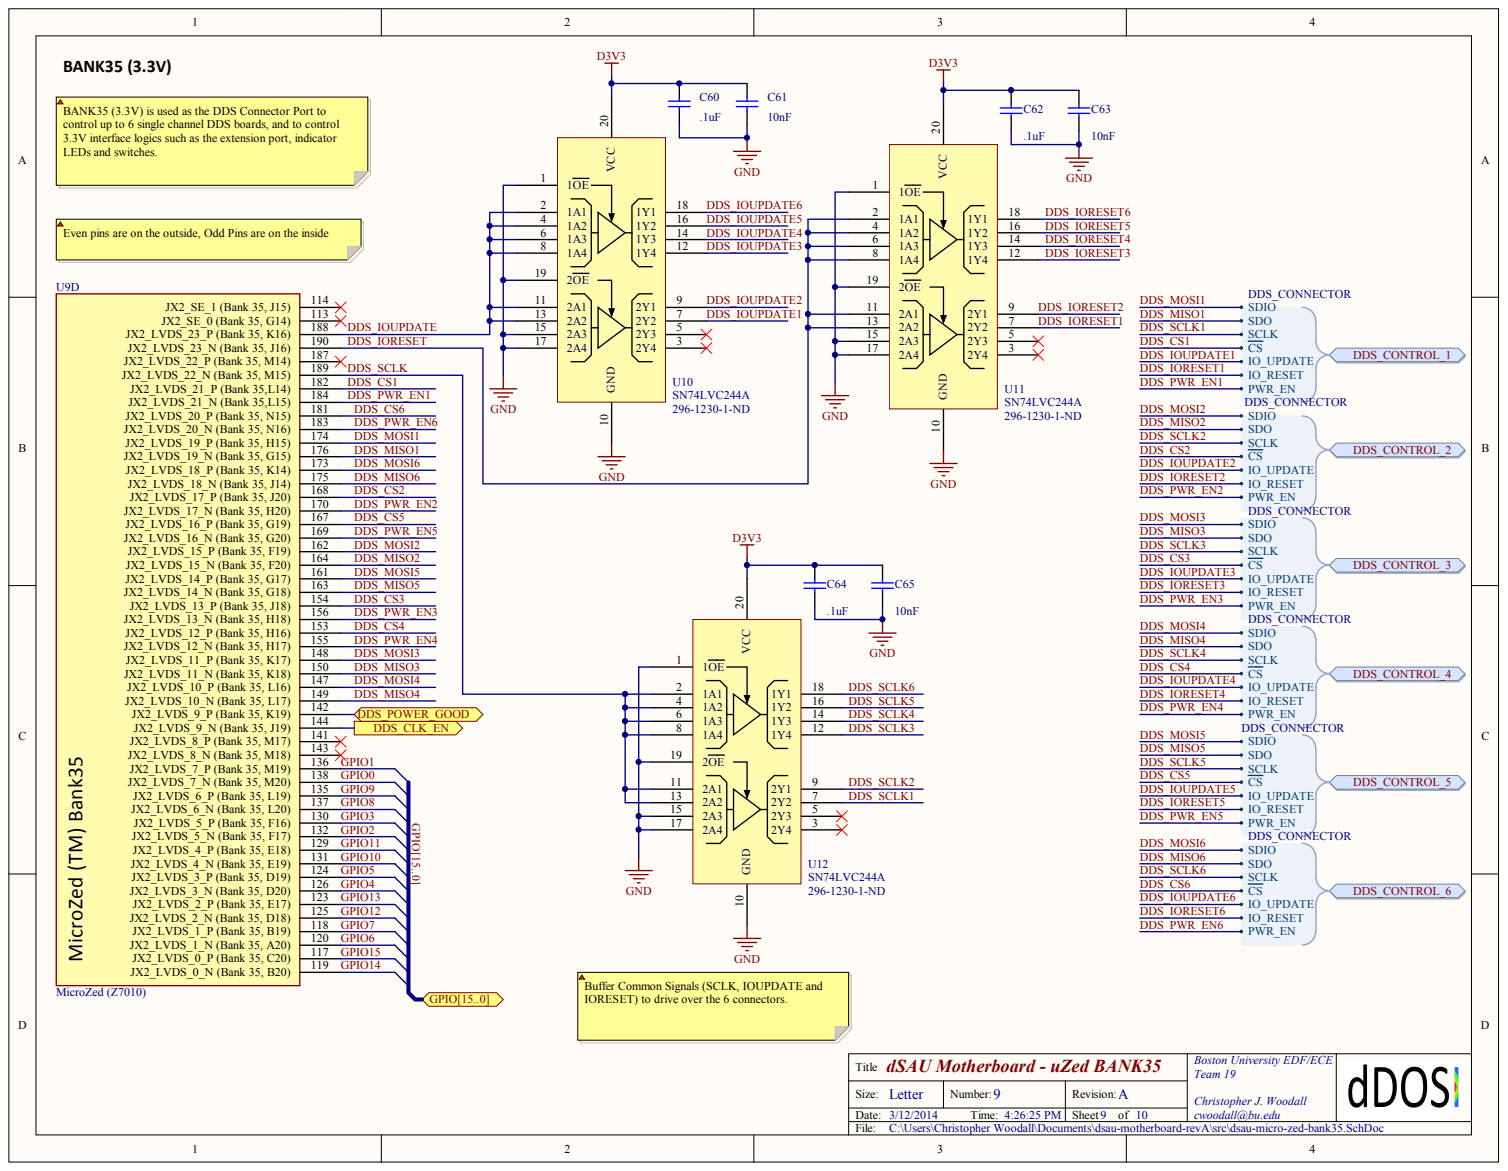
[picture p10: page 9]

1A 2 1A 3 1A 4

DDS_MOSI6 DDS_MISO6

DDS_CS 2 DDS_PWR_EN2 DDS_CS 5 DDS_PWR_EN5 DDS_MOSI2 DDS_MISO2 DDS_MOSI5 DDS_MISO5 DDS_CS 3 DDS_PWR_EN3 DDS_CS 4 DDS_PWR_EN4 DDS_MOSI3 DDS_MISO3 DDS_MOSI4

4 | | DDS_SCLK 5

T it l e | Boston University EDF/ECE Ch ristopher J. Woodall cwoodall@ bu.edu

Size : | Number: | Rev i s i o n :

3/12/201 4 T ime: 4:26:25 P M | | Sheet o f 10

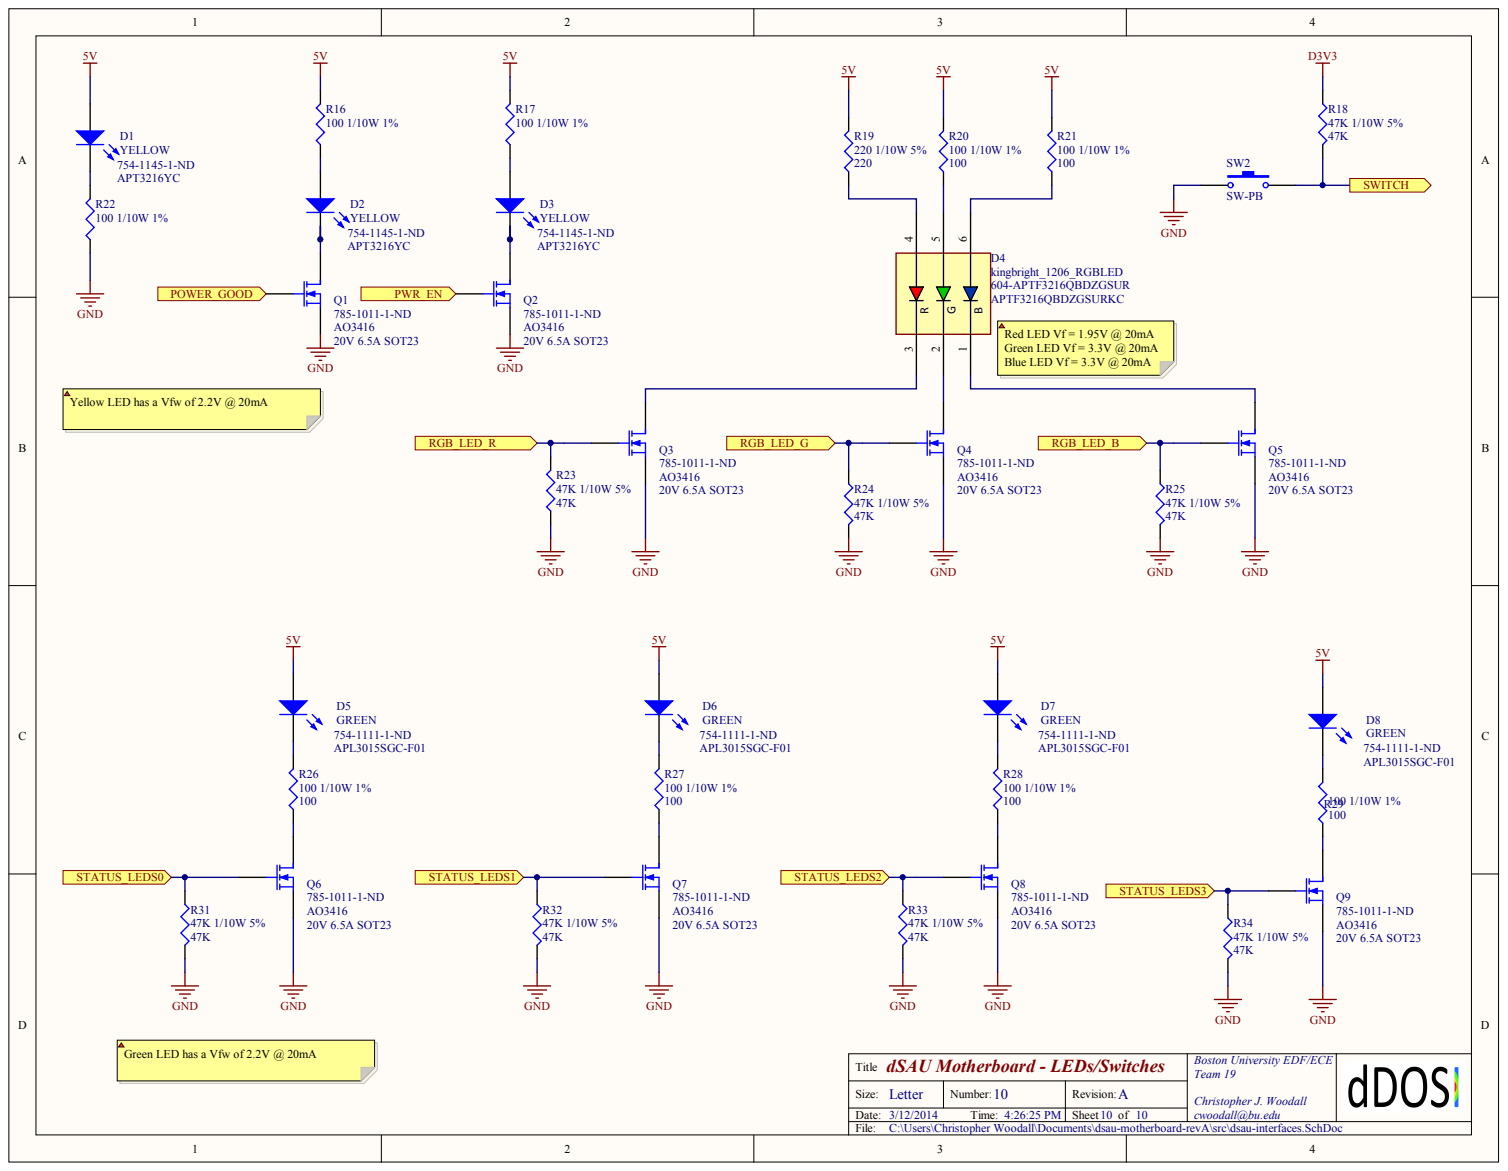
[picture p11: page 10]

Yellow LED has a Vfw of 2.2V @ 20mA

Green LED has a Vfw of 2.2V @ 20mA

dSAU Motherboard - LEDs/Switches
Title

Boston University EDF/ECE

C:\Users\Christopher Woodall\Documents\dsau-motherboard-revA\src\dsau-interfaces.SchDoc

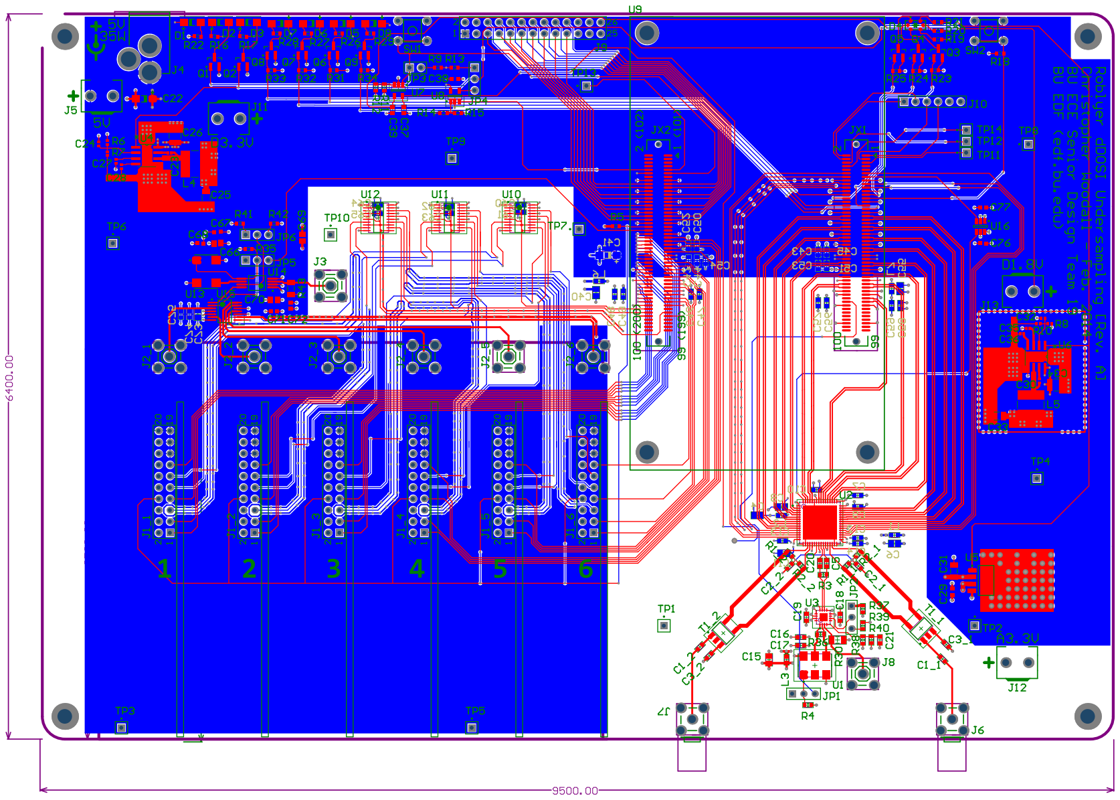
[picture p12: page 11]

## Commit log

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2014-01-10 Added "MicroZed" component to lib\dsau-motherboard.SchLib. This component is represented in a manner which abstracts it away from its physical layout. Each FPGA Bank is represented as a separate modu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
    No mechanical layout has occured yet.
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2014-01-11 Added pin numbers to pcb layout for FCI_61083-101400LF in lib/dsau-motherboard.PcbLib. checked against IO Carrier Mechanical drawing, seems correct... Not 100% sure though. Proceed with caution
2014-01-11 Added the MicroZed PCB footprint, which is made up of two of the FCI connectors. Pins are numbered correctly (double check). Added silkscreen numbering and indicators of JX1 and JX2 mating connectors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
2014-01-14 Changed mounting hole size of microzed board to the correct 125mil hole size.
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2014-01-14 - Fixed arcs on lib/dsau-motherboard.PcbLib: - Added "Top Solder" layer over the arcs so that they can be soldered to (equivalent to removing the solder mask). - Moved pads from rectangle to rounded 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
2014-01-14 Added CUI_PJ_002BH_SMT to the lib/dsau-motherboard.PcbLib. - Holes in correct place according to datasheet - Includes a 3d body model
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2014-01-17 - Corrected RGBLED_1206_KINGSBRIGHT: - 3d Model offset - Solder Mask layer problem (TOP SOLDER) Added arcs to pads 4, 5 & 6
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2014-01-17 Started Clock Schematic
    Added a testpoint part and a jumper part to lib/dsau-motherboard.SchLib
    [dsau-adc-frontend.SchDoc, dsau-adc.SchDoc, dsau-motherboard-revA.PrjPcb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]
2014-01-17 - Edited the jumper in lib/dsau-motherboard.SchLib. - Finished FULL clock network, with jumpers and reconfiguration options. (WATCH)
    [dsau-adc.SchDoc]
2014-01-17 Moved the FOX oscillator (250MHz)'s power to a separate symbol for inclusion on the power page.
    - Moved from ports to harnesses + port to reduce wire clutter on top level.
    [dsau-adc-frontend.SchDoc, dsau-adc.SchDoc, dsau-motherboard-revA.PrjPcb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]
2014-01-17 Updated parameters of sheet to reflect revision number... Need to keep maintaining
    Added harness file
    [dsau-adc-frontend.SchDoc, dsau-adc.SchDoc, dsau-motherboard-top.SchDoc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]
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2014-01-19 - Added dds connector harnesses.
    - Added connectors for dds as a subsheet to reduce the work required to make a change to their pin out. Waiting on @tnadov to get the DDS pin config to me.
    - Initial Annotation done
    - ProTip: When annotating multi-part components be sure to **lock** the subpart, otherwise the annotation tool WILL change it... This sucks and you don't want it.
    [dsau-adc-frontend.SchDoc, dsau-adc.SchDoc, dsau-dds-connector.SchDoc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]
2014-01-19 added the pinout for the expansion port. Not wired up to microzed yet
    [dsau-micro-zed.SchDoc, dsau-motherboard-top.SchDoc]
2014-01-19 Updated dsau-micro-zed.SchDoc to be in the src folder. Also added ports to it.
    [dsau-micro-zed.SchDoc, dsau-motherboard-top.SchDoc]
2014-01-19 Fixed ADC Pinout naming into harness.
    [dsau-adc.SchDoc, dsau-micro-zed.SchDoc, dsau-motherboard-revA.PrjPcb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]
2014-01-19 Added microzed to page.... Takes up a lot of room.... May need to shrink components inorder to more reasonably fit
    [dsau-adc.SchDoc, dsau-micro-zed.SchDoc, dsau-motherboard-revA.PrjPcb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]
2014-01-19 Updated the lib/dsau-motherboard.SchLib so that multipart symbols are locked in their assignment by default to prevent the annotator from going crazy.
    [dsau-adc.SchDoc, dsau-power.SchDoc]
2014-01-22 - Minor changes in lib/dsau-motherboard.SchLib involved in pinspacing in microzed for a more condensed component
    - Moved Bank13 into Power (also includes no connects)
    - Added configuration note for Oscillator configurations
    [dsau-adc.SchDoc, dsau-micro-zed.SchDoc, dsau-motherboard-top.SchDoc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]
2014-01-22 Added src/dsau-micro-zed-bank34.SchDoc and src/dsau-micro-zed-bank35.SchDoc to hold connections to the microzed in an easier to handle manner.
    Bank34 will be a 1.8V bank
    Bank35 will be a 3.3V bank
    [dsau-adc-frontend.SchDoc, dsau-adc.SchDoc, dsau-dds-connector.SchDoc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]
2014-01-22 - Added notes for: - BANK500 not available on Z7010 based MicroZeds (which is what we are using) - BANK13 is not being used (as a design choice) - Moved Microzed BANK13 from dsau-power.SchDoc to dsau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
    [dsau-micro-zed-bank34.SchDoc, dsau-micro-zed-bank35.SchDoc, dsau-micro-zed.SchDoc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]
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2014-01-22 Fixed directionality of JTAG port pins
    [dsau-micro-zed.SchDoc, dsau-motherboard-top.SchDoc]
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2014-01-22 Added Titles to all relevant sheets. In the format
    dSAU Motherboard - SHEETNAME
    [dsau-adc-frontend.SchDoc, dsau-adc.SchDoc, dsau-dds-connector.SchDoc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]
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2014-01-24 Resolves #4.
    [dsau-micro-zed-bank35.SchDoc]
2014-01-24 Updated connector annotations, added decoupling capcitor (C7) and updated some comments to reveal relevant information.
    [dsau-adc-frontend.SchDoc, dsau-adc.SchDoc, dsau-dds-connector.SchDoc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]
2014-01-25 Connected GPIO into the microzed via the GPIO[0..16] bus.
    Resolves #13.
    [dsau-micro-zed-bank35.SchDoc, dsau-motherboard-revA.PrjPcb, dsau-motherboard-top.SchDoc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]
2014-01-25 - Added LEDS to interface and RGB Leds to interface - 1 power on LED - 4 Status LEDS - 1 RGB LED
    - Added ports onto schematic sheet.
    [dsau-motherboard-top.SchDoc]
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2014-01-25 Added info that BANK13 (not BANK500) is not available on the Z7010. Added to the lib/dsau-motherboard.SchLib as well. This is important to know.
    [dsau-interfaces.SchDoc, dsau-micro-zed-bank35.SchDoc, dsau-micro-zed.SchDoc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]
2014-01-25 - Made Test Point Shorter - Resolved #8 and Resolved #9 - LEDs and Switches hooked up - Hooked up new GPIO resolving #14.
    [dsau-adc-frontend.SchDoc, dsau-adc.SchDoc, dsau-dds-connector.SchDoc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]
2014-01-25 Resolves #14 : GPIO hooked up correctly. Resolves #10 : Switch hooked up.
    Resolves #12 : Hooked up most of the Microzed Control Pins, most
    are already taken care of, but do note that PG_MODULE and VCCIO_EN still need to be taken care of and new issues have been reported for them Issues #
    Ammend: Did not save all important files.
    [dsau-interfaces.SchDoc, dsau-micro-zed-bank35.SchDoc, dsau-micro-zed.SchDoc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]
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2014-01-27 +tnadovich
    I changed the pinout of the DDS Connector to the following
    1 SDIO
    2 NC
    3 SDO
    4 NC
    5 SCLK
    6 NC
    7 CS#
    8 GND
    9 IO_UPDATE
    10 GND
    11 IO_RESET
    12 GND
    13 PWR_EN
    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
    [dsau-dds-connector.SchDoc]
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2014-01-27 Fixed bus based issue, where nets for GPIO were not actually connected.
    [dsau-micro-zed-bank35.SchDoc, dsau-micro-zed.SchDoc, dsau-motherboard-top.SchDoc]
2014-01-27 Fixed initial conditions of dsau-interfaces.SchDoc fixing #19
    [dsau-interfaces.SchDoc, dsau-micro-zed.SchDoc, dsau-motherboard-revA.PrjPcb]
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2014-01-29 Removed ALT_CLK_{P,N} which were going from the ADC to FPGA and worked on the SMA connection. REMEMBER: +cwoodall SMA needs 100-Ohms termination...
    [dsau-adc.SchDoc, dsau-micro-zed-bank34.SchDoc, dsau-micro-zed-bank35.SchDoc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]
2014-01-29 Moved from ADS62P49 to ADS62P49_SINLGE Schematic Symbol, which is a single part instead of a bunch of parts...
    [dsau-adc-frontend.SchDoc, dsau-adc.SchDoc, dsau-dds-connector.SchDoc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]
2014-01-29 Moved Clock Oscillator to a one part schematic part... Everything looks a little easier to understand
    [dsau-adc-frontend.SchDoc, dsau-adc.SchDoc, dsau-dds-connector.SchDoc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]
2014-02-02 Swapped sides of the ADS62P49 analog/digital power connections to match grounds and pins
    [dsau-adc.SchDoc]
2014-02-02 Added decoupling/supply filtering network to related components on the ADC sheet. Fixed an error in the ADC_SPI_CONFIG harness.
    [dsau-adc-frontend.SchDoc, dsau-adc.SchDoc, dsau-micro-zed-bank34.SchDoc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]
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2014-02-03 Selected appropriate transistors for LED circuitry. moved to a GPO/GPI extension port instead of a GPIO extension port
    4 outs, 4 ins. Verify that this is enough (can implement UART, SPI (master and slave) and basic TTL/CMOS pulses)
    [dsau-adc-frontend.SchDoc, dsau-adc.SchDoc, dsau-dds-connector.SchDoc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]
2014-02-03 Added buffered IO with the SN74LVC244A (and appropriate schematic symbol). Also added a TSSOP-20 PCB symbol for it and all appropriate manufacturer and supplier information.
    [dsau-adc-frontend.SchDoc, dsau-adc.SchDoc, dsau-dds-connector.SchDoc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]
2014-02-05 - Added component values, need to associate footprints (TODO). - Merged AGND and DGND - Merged Tom's power schematics into my design - Buffered I/Os (documented in senior design notebook) - Selected 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
    [dsau-adc-frontend.SchDoc, dsau-adc.SchDoc, dsau-dds-connector.SchDoc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]
2014-02-05 Made sure all ports where present on all sheets. Ready to receive modifications from +tnadovich for the power schematic
    [dsau-adc-frontend.SchDoc, dsau-adc.SchDoc, dsau-dds-connector.SchDoc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]
2014-02-06 - Updated annotations - Added LED supplier and part numbers. - Added some connector parts
    [dsau-adc-frontend.SchDoc, dsau-adc.SchDoc, dsau-dds-connector.SchDoc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]
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2014-02-07 - Added DDS clock generation path. - Added correct power circuitry and power good circuitry - Removed GPIO buffers
    TODO:
    - Add series resistance on GPIO (~30 ohms)
    - Add proper buffers to DDS (for driving to the 6 offboard DDS boards).
    [dsau-adc-frontend.SchDoc, dsau-adc.SchDoc, dsau-dds-clock.SchDoc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]
2014-02-08 - Tweaked decoupling networks to include 10pF and 10nF caps - Added in all required part numbers - Added in buffers for SPI to DDS (common signals only)
    [dsau-adc-frontend.SchDoc, dsau-adc.SchDoc, dsau-dds-clock.SchDoc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]
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2014-02-11 - Associated footprints - Added notes and new descriptions of parts - created and updated BOM for order - type found in corrected in the ADC schematic part. Changed text "DAC" to "ADC". - Confirmed p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
    [dsau-adc-frontend.SchDoc, dsau-adc.SchDoc, dsau-dds-clock.SchDoc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]
2014-02-13 Made a large number of changes relating to parts selection, power circuit (thanks to Thomas Nadovich) and power enable signals so that they are handled correctly.
    [dsau-adc-frontend.SchDoc, dsau-adc.SchDoc, dsau-dds-clock.SchDoc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]
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2014-03-03 Most intermediate routing done!
    - Changed size to 9.5" from 9" to add some extra clearance on the side of the board.
    - Power planes completed
    - ADC routed.
    # Todo
    - Final routing
    - Final DDS layout
    - Review
    - Beautification (notes, proper designator placement, etc).
    [dsau-adc-frontend.SchDoc, dsau-adc.SchDoc, dsau-dds-clock.SchDoc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]
2014-03-03 - Routed clocks for DDS. - Checked clearance between DDS and uZed - Routed Power Enable network.
    [dsau-micro-zed.SchDoc, dsau-motherboard-revA.PcbDoc]
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2014-03-05 [x] Need thermal reliefs on thru-hole plane connections (many places) [x] Also to bottom layer 5V plane [x] Need thermal reliefs on SMT connections to bottom layer in 5V area [x] The PWR_EN trace goi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
    [dsau-motherboard-revA.PcbDoc, dsau-motherboard-revA.PrjPcb, dsau-motherboard-revA.xls]
2014-03-05 [x] Added guard GND traces to SCLK [x] Made U2 and U3 pads larger and resolved issues with soldermask between pins and EPAD.
    [dsau-motherboard-revA.PcbDoc]
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
